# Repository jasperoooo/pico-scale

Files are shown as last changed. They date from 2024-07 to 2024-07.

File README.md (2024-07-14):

# pico-scale
0.1g scale with a Raspberry Pi Pico, using a load cell with HX711 breakout board.

## Libraries
For this project, I used the Adafruit SSD1306 library and Lopy's HX711 library.
- https://github.com/adafruit/micropython-adafruit-ssd1306
- https://github.com/geda/hx711-lopy

## Parts
- Raspberry Pi Pico
- 3kg load cell with HX711 breakout board
- 0.96" 128x64 SSD1306 OLED screen
- 18650 battery and single cell 18650 battery holder
- TP4056 USB-C Li-Ion charger
- KCD1-101 2 Pin rocker switch
- Metal push button I had laying around, M15 thread size
- Threaded inserts:
  - 8x M2
  - 2x M3
- Screws (all DIN 912 hex socket head cap screws):
  - 2x M3 max 20mm
  - 2x M2x4mm
  - 2x M2 max 6mm
  - 4x M2 max 20mm
  - 2x M4 max 20mm
  - 2x M4 max 20mm
- Additional Supplies:
  - Wires
  - Soldering equipment
  - Hot glue to secure 18650 and TP4056

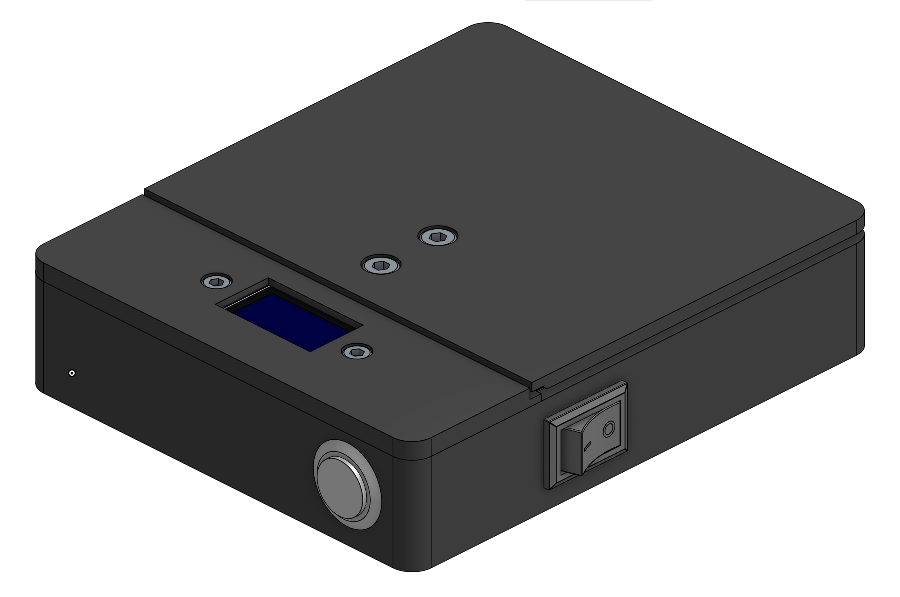
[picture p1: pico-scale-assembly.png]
pico-scale-assembly


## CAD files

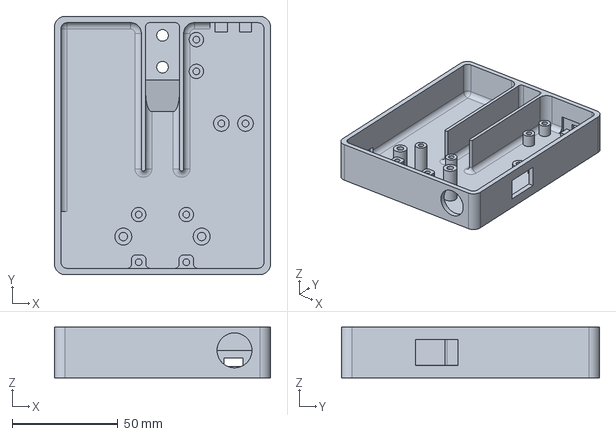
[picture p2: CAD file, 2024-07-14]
CAD/pico-scale bottom.step
102.0 x 122.0 x 24.0 mm

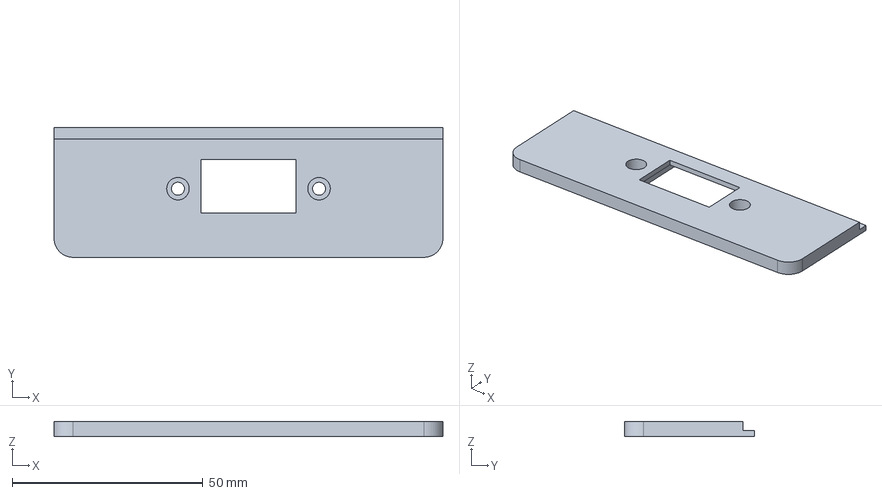
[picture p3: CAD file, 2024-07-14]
CAD/pico-scale displaylid.step
102.0 x 34.0 x 4.00 mm

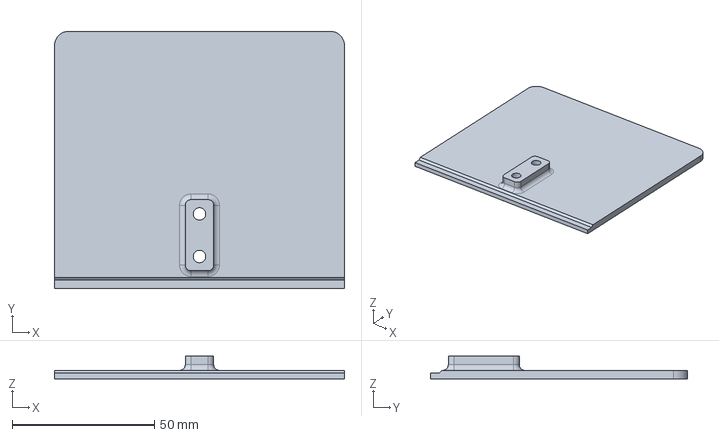
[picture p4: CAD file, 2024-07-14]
CAD/pico-scale weighing plate.step
102.0 x 90.5 x 8.00 mm

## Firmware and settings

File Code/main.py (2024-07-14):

from machine import Pin, SoftI2C, ADC
import ssd1306
import random
from time import *
from hx711 import HX711
import sys

# OLED init
i2c = SoftI2C(scl=Pin(17), sda=Pin(16))
oled_width = 128
oled_height = 64
oled = ssd1306.SSD1306_I2C(oled_width, oled_height, i2c)
oled.fill(0)

# VSYS ADC init
adcpin = machine.Pin(29, machine.Pin.IN)
vsys = machine.ADC(29)
conversionFactor = 3 * (3.3/65535)
batteryVoltage = round(vsys.read_u16() * conversionFactor, 1)

# Check if battery is below 3V. It's not really empty but too empty to run the Pico
if batteryVoltage < 3:
    oled.text("BATTERY EMPTY.", 10, 20)
    oled.text("PLEASE RECHARGE.", 0, 36)
    oled.show()
    sys.exit()

# HX711 init
hxClock = 19
hxData = 18
hx = HX711(18, 19, 128) # Data Pin, Clock Pin, Gain

knownWeight = 30 # in g
rawKnownWeight = 20830 # raw value of known weight
scaleFactor = rawKnownWeight / knownWeight

hx.tare()
oled.text("Taring scale...", 0, 0)
oled.show()

hx.set_scale(scaleFactor)
weightTreshold = 0.2 # dead zone for the scale so it's stable at 0g

oled.text("Scale tared!", 0, 16)
oled.show()

#tare button init
last_interrupt_time = 0
debounce_time = 2000 # time before another button press is recognized, in ms
buttonSource= Pin(14, mode=Pin.OUT, value=1) # high GPIO pin next to the button GPIO. Was easier to wire for me, can be any 3.3V source

def tare_button_pressed(pin):
    global last_interrupt_time
    current_time_tare = ticks_ms() # start timer
    
    if current_time_tare - last_interrupt_time > debounce_time: # if timer is longer than 2s
        last_interrupt_time = current_time_tare
        
        oled.fill(0)
        oled.text("Taring scale...", 0, 0)
        oled.show()
        
        hx.tare()
        
        oled.text("Scale tared!", 0, 16)
        oled.show()
        oled.fill(0)
     
tare_button = Pin(15, Pin.IN, Pin.PULL_DOWN)
tare_button.irq(trigger=Pin.IRQ_RISING, handler=tare_button_pressed)

# Flowrate calculation
class Flowrate:
    def __init__(self):
        self.previous_weight = 0.0
        self.previous_time = ticks_ms()

    def calculate_rate(self, current_weight):
        current_time = ticks_ms()
        elapsed_time = ticks_diff(current_time, self.previous_time) / 1000.0  # Convert ms to seconds

        if elapsed_time == 0:
            return 0  # Avoid division by zero

        weight_difference = current_weight - self.previous_weight
        rate = round(weight_difference / elapsed_time, 1)  # grams per second

        # Update previous values
        self.previous_weight = current_weight
        self.previous_time = current_time

        return rate

flowrate = Flowrate()

while True:
    oled.fill(0) # reset OLED to blank
    
    batteryVoltage = round(vsys.read_u16() * conversionFactor, 1) # get battery voltage
    
    weight = hx.get_units(times=6) # get weight, times value is how many values are averaged
    roundedWeight = round(weight, 1)
    
    if -weightTreshold < weight < weightTreshold: # dead zone around 0g
        finalWeight = 0
    else:
        finalWeight = roundedWeight
    
    rate = flowrate.calculate_rate(finalWeight) # get flowrate
    
    # right aligns weight text on the OLED. Depending on digit count, text distance from the left screen edge decreases
    if finalWeight == 0:
        weightSpacing = 68
    elif 0 < abs(finalWeight) < 10:
        weightSpacing = 48
    elif 10 <= abs(finalWeight) < 100:
        weightSpacing = 32
    elif 100 <= abs(finalWeight) < 1000:
        weightSpacing = 16
    elif 1000 <= abs(finalWeight) <= 3000:
        weightSpacing = 0
    elif abs(finalWeight) > 3000:
        weightSpacing = 32
    
    # right alignment for pos or neg values
    if finalWeight >= 0:
        wSpacing = weightSpacing + 16
    elif finalWeight < 0:
        wSpacing = weightSpacing
    
    # right alignment for flow rate, same principle as weight but lower spacings because the text is smaller
    if 0 <= abs(rate) < 10:
        rateSpacing = 70
    elif 10 <= abs(rate) < 100:
        rateSpacing = 62
    elif 100 <= abs(rate) < 1000:
        rateSpacing = 54
    elif 1000 <= abs(rate) <= 3000:
        rateSpacing = 46
    
    if rate >= 0:
        rSpacing = rateSpacing + 8
    elif rate < 0:
        rSpacing = rateSpacing
    
    # error if weight is above 3kg, which is max for my load cell
    if finalWeight > 3000:
        displayWeight = "MAX"
    else:
        displayWeight = str(finalWeight)
        oled.text("g", 102, 30)
        oled.text(str(rate) + "g/s", rSpacing, 48)
    
    oled.text_scaled_16x16(displayWeight, wSpacing, 22) # larger text for weight
    oled.text("max. 3kg", 0, 0)
    
    batteryPercentage = ((batteryVoltage -3)/(4.2 - 3)) * 100 # calculate battery percentage with 4.2V max and 3V min
    displayBattery = str(int(batteryPercentage)) + "%"        
    oled.text(displayBattery, 104, 0)
    
    oled.show()
    sleep(0.1)

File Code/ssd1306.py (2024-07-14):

#MicroPython SSD1306 OLED driver, I2C and SPI interfaces created by Adafruit

import time
import framebuf

# register definitions
SET_CONTRAST        = const(0x81)
SET_ENTIRE_ON       = const(0xa4)
SET_NORM_INV        = const(0xa6)
SET_DISP            = const(0xae)
SET_MEM_ADDR        = const(0x20)
SET_COL_ADDR        = const(0x21)
SET_PAGE_ADDR       = const(0x22)
SET_DISP_START_LINE = const(0x40)
SET_SEG_REMAP       = const(0xa0)
SET_MUX_RATIO       = const(0xa8)
SET_COM_OUT_DIR     = const(0xc0)
SET_DISP_OFFSET     = const(0xd3)
SET_COM_PIN_CFG     = const(0xda)
SET_DISP_CLK_DIV    = const(0xd5)
SET_PRECHARGE       = const(0xd9)
SET_VCOM_DESEL      = const(0xdb)
SET_CHARGE_PUMP     = const(0x8d)


class SSD1306:
    def __init__(self, width, height, external_vcc):
        self.width = width
        self.height = height
        self.external_vcc = external_vcc
        self.pages = self.height // 8
        # Note the subclass must initialize self.framebuf to a framebuffer.
        # This is necessary because the underlying data buffer is different
        # between I2C and SPI implementations (I2C needs an extra byte).
        self.poweron()
        self.init_display()

    def init_display(self):
        for cmd in (
            SET_DISP | 0x00, # off
            # address setting
            SET_MEM_ADDR, 0x00, # horizontal
            # resolution and layout
            SET_DISP_START_LINE | 0x00,
            SET_SEG_REMAP | 0x01, # column addr 127 mapped to SEG0
            SET_MUX_RATIO, self.height - 1,
            SET_COM_OUT_DIR | 0x08, # scan from COM[N] to COM0
            SET_DISP_OFFSET, 0x00,
            SET_COM_PIN_CFG, 0x02 if self.height == 32 else 0x12,
            # timing and driving scheme
            SET_DISP_CLK_DIV, 0x80,
            SET_PRECHARGE, 0x22 if self.external_vcc else 0xf1,
            SET_VCOM_DESEL, 0x30, # 0.83*Vcc
            # display
            SET_CONTRAST, 0xff, # maximum
            SET_ENTIRE_ON, # output follows RAM contents
            SET_NORM_INV, # not inverted
            # charge pump
            SET_CHARGE_PUMP, 0x10 if self.external_vcc else 0x14,
            SET_DISP | 0x01): # on
            self.write_cmd(cmd)
        self.fill(0)
        self.show()

    def poweroff(self):
        self.write_cmd(SET_DISP | 0x00)

    def contrast(self, contrast):
        self.write_cmd(SET_CONTRAST)
        self.write_cmd(contrast)

    def invert(self, invert):
        self.write_cmd(SET_NORM_INV | (invert & 1))

    def show(self):
        x0 = 0
        x1 = self.width - 1
        if self.width == 64:
            # displays with width of 64 pixels are shifted by 32
            x0 += 32
            x1 += 32
        self.write_cmd(SET_COL_ADDR)
        self.write_cmd(x0)
        self.write_cmd(x1)
        self.write_cmd(SET_PAGE_ADDR)
        self.write_cmd(0)
        self.write_cmd(self.pages - 1)
        self.write_framebuf()

    def fill(self, col):
        self.framebuf.fill(col)

    def pixel(self, x, y, col):
        self.framebuf.pixel(x, y, col)

    def scroll(self, dx, dy):
        self.framebuf.scroll(dx, dy)

    def text(self, string, x, y, col=1):
        self.framebuf.text(string, x, y, col)
        
    def draw_char_scaled_16x16(self, char, x, y, color=1):
        # Basic font definition for 'A', 'B', and space ' ' using hex values
        font_8x8 = {
            '0': [0x3C, 0x42, 0x46, 0x4A, 0x52, 0x62, 0x42, 0x3C],
            '1': [0x10, 0x30, 0x10, 0x10, 0x10, 0x10, 0x10, 0x7C],
            '2': [0x3C, 0x42, 0x02, 0x0C, 0x30, 0x40, 0x42, 0x7E],
            '3': [0x3C, 0x42, 0x02, 0x1C, 0x02, 0x02, 0x42, 0x3C],
            '4': [0x08, 0x18, 0x28, 0x48, 0x7E, 0x08, 0x08, 0x08],
            '5': [0x7E, 0x40, 0x40, 0x7C, 0x02, 0x02, 0x42, 0x3C],
            '6': [0x3C, 0x42, 0x40, 0x7C, 0x42, 0x42, 0x42, 0x3C],
            '7': [0x7E, 0x42, 0x04, 0x08, 0x10, 0x10, 0x10, 0x10],
            '8': [0x3C, 0x42, 0x42, 0x3C, 0x42, 0x42, 0x42, 0x3C],
            '9': [0x3C, 0x42, 0x42, 0x42, 0x3C, 0x02, 0x42, 0x3C],
            'g': [0x00, 0x1C, 0x22, 0x22, 0x1C, 0x02, 0x02, 0x1C],
            '.': [0x00, 0x00, 0x00, 0x00, 0x00, 0x00, 0x00, 0x80],  
            ' ': [0x00, 0x00, 0x00, 0x00, 0x00, 0x00, 0x00, 0x00],
            'M': [0x42, 0x66, 0x5A, 0x5A, 0x42, 0x42, 0x42, 0x42],
            'A': [0x18, 0x24, 0x42, 0x42, 0x7E, 0x42, 0x42, 0x42],
            'X': [0x42, 0x24, 0x18, 0x18, 0x18, 0x24, 0x42, 0x42],
            '-': [0x00, 0x00, 0x00, 0x7E, 0x00, 0x00, 0x00, 0x00]
        }
        
        scale = 2  # Scale each pixel to 2x2 to get 16x16 from 8x8
        x_adjust = 0  # No adjustment by default

        # Special handling for the decimal point to adjust position
        if char == '.':
            x_adjust = 14  # Adjust x position closer to the previous character

        bitmap = font_8x8.get(char, font_8x8[' '])
        
        for j in range(8):  # Row in original bitmap
            for i in range(8):  # Column in original bitmap
                if bitmap[j] & (1 << (7 - i)):  # Check each bit
                    for dy in range(scale):
                        for dx in range(scale):
                            self.framebuf.pixel(x + x_adjust + (i * scale) + dx, y + (j * scale) + dy, color)
    
    def text_scaled_16x16(self, text, x, y):
        x_offset = 0  # Start position offset for the first character
        for i, char in enumerate(text):
            if char == '.':
                # Draw the decimal point and adjust position closer to the previous character
                self.draw_char_scaled_16x16(char, x + x_offset - 6, y)  # Move the decimal point leftwards
                x_offset += 12  # Advance less after a decimal point since it occupies less space
            else:
                # Draw regular character at the current position
                self.draw_char_scaled_16x16(char, x + x_offset, y)
                x_offset += 16  # Standard advance for regular characters

            # Adjust x_offset based on character width
            if i < len(text) - 1 and text[i + 1] == '.':
                # If the next character is a decimal point, reduce the advance
                x_offset -= 6  # Reduce the advance to bring the next character (decimal point) closer
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

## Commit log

2024-07-14 CAD files, file structure
    [pico-scale bottom.step, pico-scale displaylid.step, pico-scale weighing plate.step]
2024-07-14 Update README.md
    inserted screenshot of scale
2024-07-14 Rename pico-scale assembly.png to pico-scale-assembly.png
